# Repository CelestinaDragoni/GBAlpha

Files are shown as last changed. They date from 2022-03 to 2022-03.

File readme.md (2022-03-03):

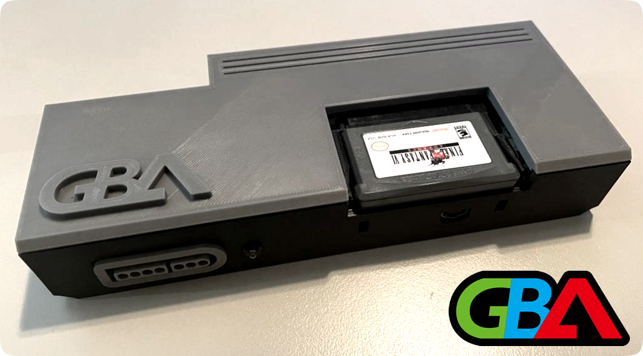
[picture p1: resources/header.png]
GBAlpha


# GBAlpha - *A Console-Like Case for Woozle's GBA Consolizer*

## Introduction
Included in this repository is a custom case design for Woozle's GBA Consolizer. This has a more console-like feel and has inspirations from various design choices from the PCEngine and NES. This case was designed around the maintainability of components inside being easy to disassemble and assemble and, unlike other available cases, this is a complete project with documentation, assembly, and printing instructions. If you want to know more around my thoughts and this project please read my forward [here](docs/introduction.md).

## Table of Contents
- [Expanded Introduction / Forward](docs/introduction.md)
- [Image Gallery](docs/gallery.md)
- [Materials Required](docs/materials.md)
- [Printing Instructions / Suggestions](docs/printing.md)
- [Assembly](docs/assembly.md)
- [STL Index](stl/readme.md)

## How To Download
Click `code` at the top and `Download Zip`, or if you're a champion checkout with `git`.

## Donate
If you like this project and want to help me stay caffeinated you can donate here: https://www.paypal.com/donate/?hosted_button_id=852RXAG6BF8Y8

## Disclaimer
This project isn't endorsed or supported by Woozle or anyone affiliated with the GBA consolizer or related projects like the GBA HD. This is my own thing. Don't go asking anyone else for support or help with this case and its designs. Thanks.

## General License



This work is licensed under a [Creative Commons Attribution-NonCommercial-ShareAlike 4.0 International License](http://creativecommons.org/licenses/by-nc-sa/4.0/).

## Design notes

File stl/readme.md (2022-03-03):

# STL Index

## Disclaimer
While you could just come in here and wing it, I highly recommend reading the [documentation](../readme.md) before throwing this into a slicer and having a go at it. This is a large print and a lengthy one at that. However, you do you.

## ./
### Cart Slot `cartslot.stl` (Required)
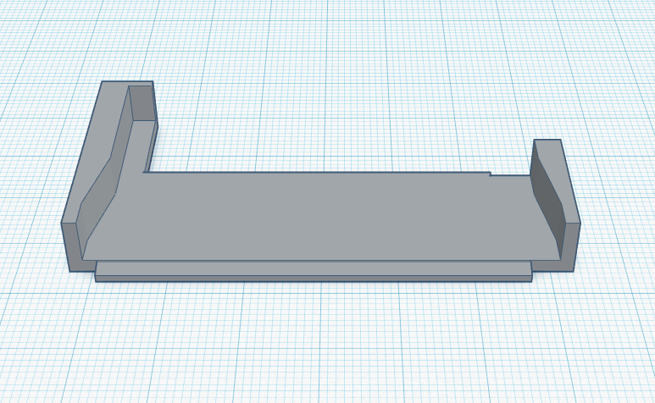
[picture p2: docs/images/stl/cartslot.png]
Cart Slot Render


This is Woozles cart slot model. This case reuses this part from that case as it was a pretty clean way of making a cart slot. You will need to print this for full assembly.

### GBA Logo `logo.stl` (Optional)
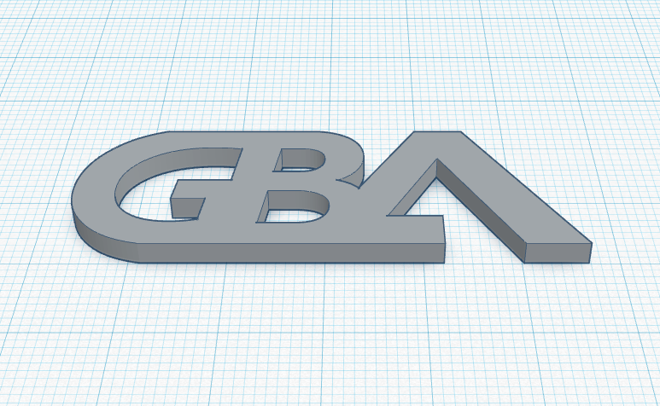
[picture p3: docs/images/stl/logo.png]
Logo Render


This logo is to be paired with the lid with no logo so could have have two colors on your lid.

## ./bases
### Base Full `base-full.stl` (Recommended Variation)
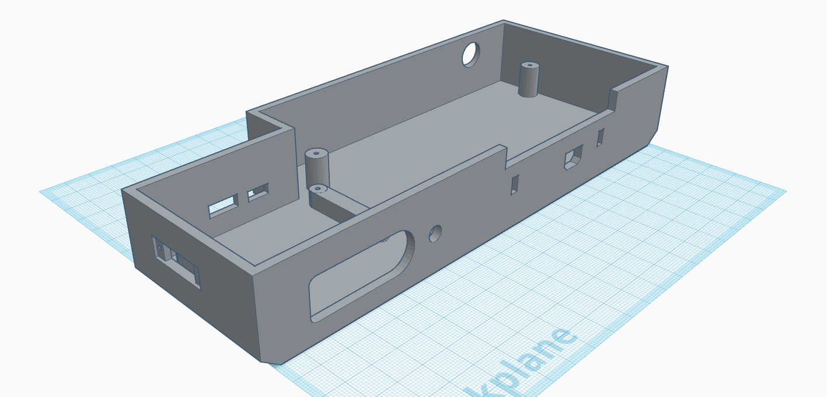
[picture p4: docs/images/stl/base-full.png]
Base Full Render


This includes everything of the base base, the GBA game link adapter slits, microphone jack in the back, etc.

### No GBA Game Link `base-no-gba.stl` (Optional Variation)
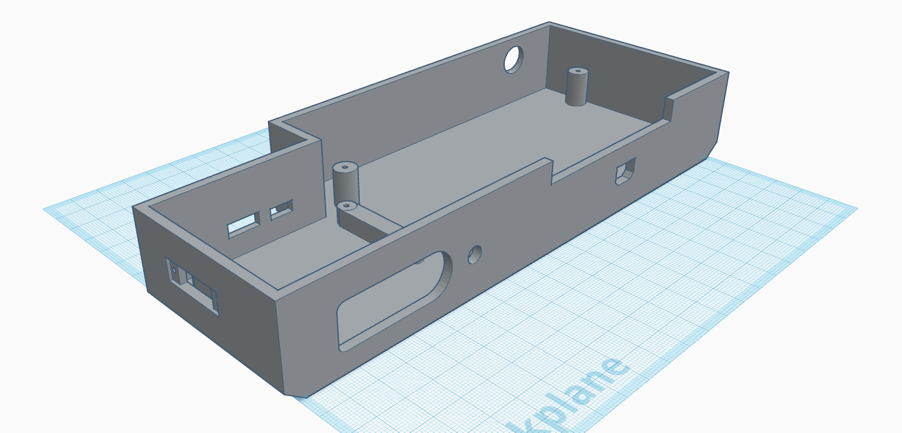
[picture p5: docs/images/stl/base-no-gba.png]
Base No GBA Render


This variation of the base has no slits for the GBA link cable accessories though still provides the GB link cable port. Outside of maybe the infrared adapter, you're likely not going to be sitting with two TVs or switching inputs to play four swords or search for Triforce pieces in Wind Waker. This is makes the front of the case much cleaner and is a good variation for those who don't care about GBA connectivity.

### No Microphone Port `base-no-mic.stl` (Optional Variation)
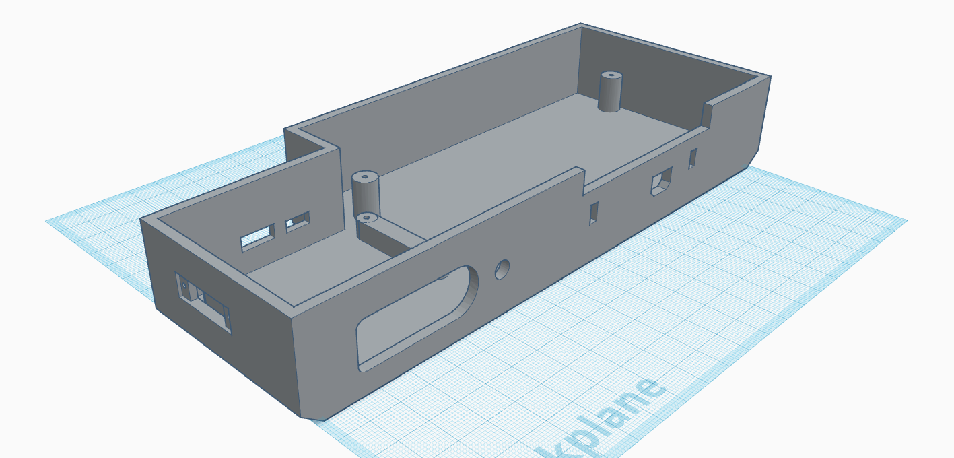
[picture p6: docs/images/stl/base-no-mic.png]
Base No Mic Render


This variation of the base has no microphone port on the back. This is provided to those who don't need access to it and DVI+ works just fine and want a cleaner back.

### No GBA Game Link & No Mic `base-no-gba-no-mic.stl`  (Optional Variation)
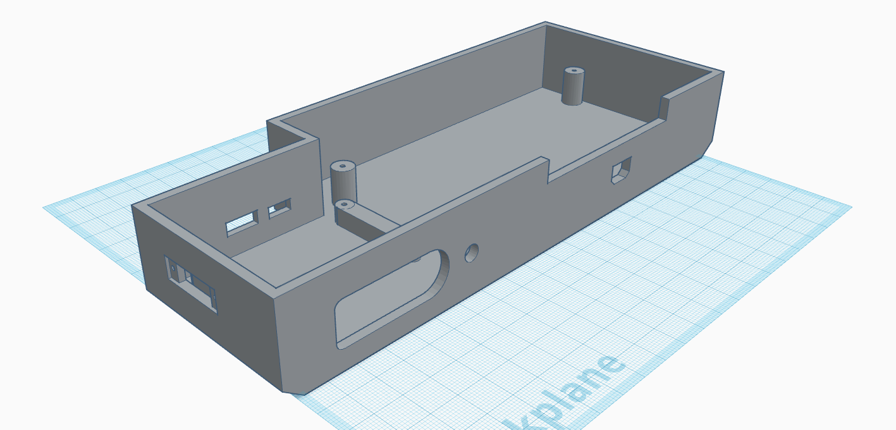
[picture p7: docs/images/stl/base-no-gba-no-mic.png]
Base No GBA No Mic Render


Combines the no microphone port and the lack of GBA game link slits.

### Absolute Minimalism `base-minimal.stl` (Optional Variation)
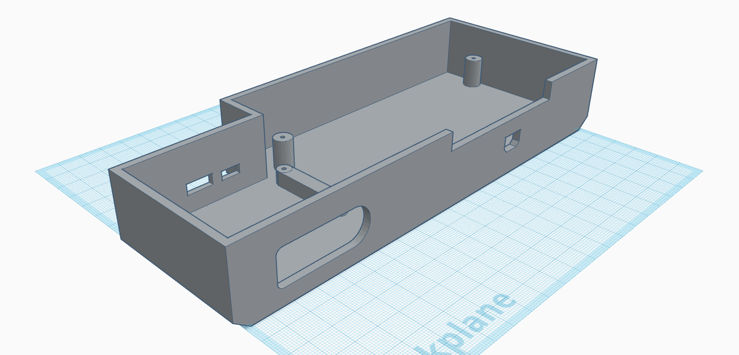
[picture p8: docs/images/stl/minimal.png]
Base Minimal Render


Removes GBA game link slits, LED hole, microphone jack, and power switch. Truth be told when I originally was just modifying Woozle's case this was what I was aiming for so I could just not have to do any work and just get a USB PSU with a power switch on it (Like one used for a Raspberry Pi). This is a minimum effort and minimum part case and all you'll need outside of the mod itself is eight (8)  `M2*6` screws.

**Note:** To use this variation you will need to solder bridge the first two (left to right) pads of the power switch area (P2 and P3) on the PCB so that when it is plugged in it will stay on. Honestly trivial thing to do considering you already did the rest of the mod.

## ./lids
### Lid With Logo `lid-full.stl` (Recommended Variation)
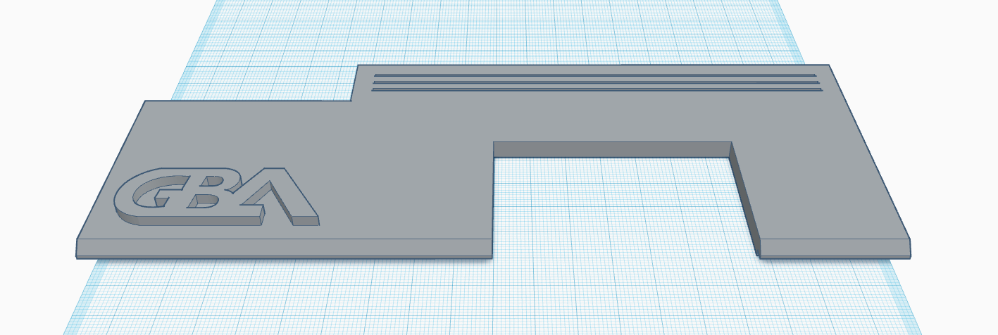
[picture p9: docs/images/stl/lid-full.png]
Lid Full Render


This comes with the GBA logo on the top already embossed on.

### Lid With Without Logo `lid-no-logo.stl` (Optional Variation)
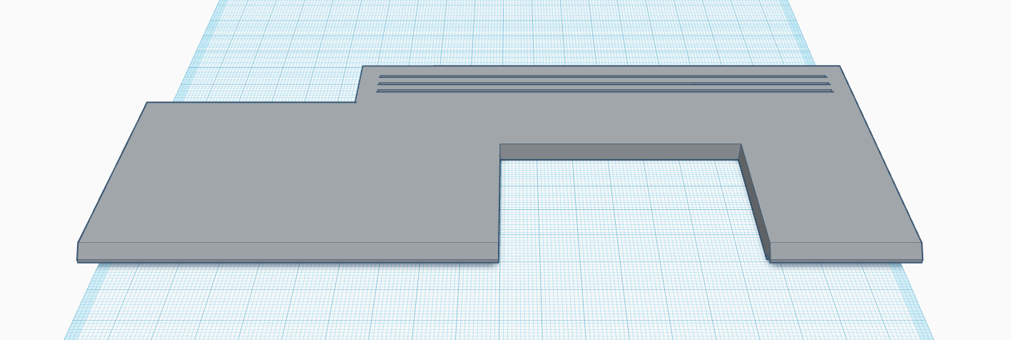
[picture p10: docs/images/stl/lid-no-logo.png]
Lid No Logo Render


This is the same lid but without the logo. You could just print this and use it without a logo at all OR you could print the logo by itself (see `./logo.stl`) in another color and glue/attach it to this lid to make a duotone lid. Alternatively if you have an IDEX 3D printer you could just combine those two models and print with two colors.

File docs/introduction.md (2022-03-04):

## Navigation

- [Home](../readme.md)
- [Expanded Introduction / Forward](introduction.md)
- [Image Gallery](gallery.md)
- [Materials Required](materials.md)
- [Printing Instructions / Suggestions](printing.md)
- [Assembly](assembly.md)
- [STL Index](../stl/readme.md)

# Expanded Introduction / Forward
This includes all of my thoughts around this project and various rants. If you're uninterested in reading this please feel free to skip along to the materials list.

## Who Am I?
I'm a Software Engineer from Raleigh NC and a retro gaming enthusiast. I own a few modded consoles and worship our lord and savior ***Lord Voultar*** ([Shop](https://voultar.com/), [YouTube](https://www.youtube.com/c/Voultar)). Unrelated, I'm also a cat girl omnicrafter in Final Fantasy XIV.

## Why Did  I Make This?
About six months ago I ordered a kit from game-tech.us and it finally came in. It came with the v2 kit (FFC/Flex Cables) and the Laser Bear Industries case. After getting the kit installed on the hardware itself it was time for assembly into the chassis.... That would end up being a disaster and send me down this rabbit hole of engineering this case.

## The Issues With Existing Cases

### Short Notice Before We Proceed
I want to be clear, I'm not putting down anyone's work  or their contribution to the community efforts. I (personally) appreciate everything everyone does to help move these projects along and makes things awesome. However, I think criticism is warranted to help make things better because feedback is rarely given around these projects.

---

### Laser Bear Industries Case
Case Link: https://www.laserbear.net/products/gba-consolizer-shell-laser-bear-version

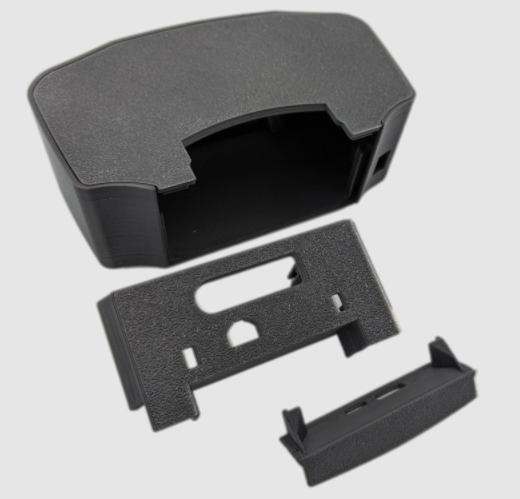
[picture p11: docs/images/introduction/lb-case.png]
LB Case


*Source: Laser Bear Industries*

I want to say some positives first off before I really dive into what I dislike about this case.

- It was extremely well printed and clean.
- The components were well fit (too well fit, and we'll get into that in a moment).
- The case came with everything you needed to assemble it.
- They also provide STL so you can download it and print it at home: https://www.laserbear.net/pages/downloads

#### Problem 1: Too Tight of Fit, Tight Tolerances
Getting things in there is quite easy if you follow how to do it, however if something came loose or something is borked that you didn't noticed before assembly, good luck getting your components out of the case without breaking it in half (which is what happened eventually).

The part to assemble the back and the front where the SFC/SNES port is have to be perfectly align, the tolerances were so tight you had to really put force down on these to get them in and snap. I really dislike this, I would have much preferred a mounting setup that would require hardware.

#### Problem 2: The Power Switch
You know, the consolizer has a place to put pins for a DuPont connector or a surface mount switch so I find it absolutely wild that this case didn't have the clearance to do so. Furthermore- the power switch 'bracket' (the place on the side of the case to insert the PCB) is too hard to get to and too hard to assemble.

#### Problem 3: Design (Subjective)
I think it's an unattractive case and still has that project box feel. I'm not about it, I also don't like the power switch cover I think it's tacky and would have just preferred the power switch PCB to be mounted closer so I can just use the vanilla switch. However this opinion is on me and my tastes and there is nothing inherently wrong about it.

---

### Woozle's GBA Consolizer Enclosure
Case Link: https://www.thingiverse.com/thing:4522648

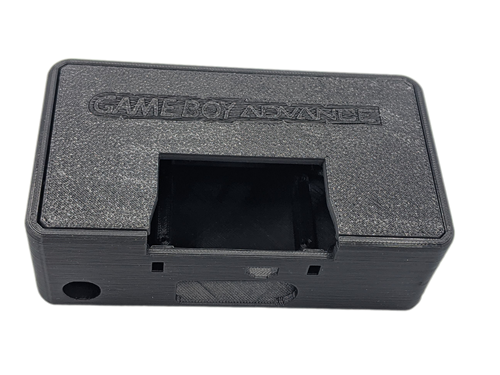
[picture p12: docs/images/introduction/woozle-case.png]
Woozle Case


*Source: Laser Bear Industries*

**I actually really like this case** and after the debacle with the LB case I decided to print this one up at home (Note, prior to buying the kit months ago I didn't have a printer at the time, I do now). Let's get into what I like about this case:

- Pretty easy to print which is good (with some exceptions we'll get into that shortly)
- Pretty hefty and nice feeling (had some weight which was a complaint about the LB version)
- Hardware mounting for the consolizer PCB and the GBA PCB
- Well fitting but enough tolerances not to be a complete pain in the ass to reassemble and disassemble.
- Love the cart slot design (which would be carried over to this project)

However...

#### Problem 1 - Where Is The Documentation?
So currently on thingiverse the only thing mentioned is this:
```
Other parts:
10x4mm pin magnets (4)
10x2mm disc magnets(4)
6mm M2 screws (8)
```
This is great but:

1. Where do I source these pin/disc magnets? I scoured amazon for hours trying to find something that matches this and came up either confused or empty. I would like some examples as to what can be used so I can find the correct fitting items.
2. There is no talk about the power switch or button here. There is room for some sort of button (I've seen variations with a push button and ones with a toggle switch) but no clear definition on what I should purchase for the case.
3. What is the extra hole next to the power switch for? An LED power indicator?
4. This print will naturally build a bunch of supports that aren't required. Some guidelines on what should be supported and what shouldn't be (like overhang tolerances and angles) would be much appreciated.

#### Problem 2 - The Lid

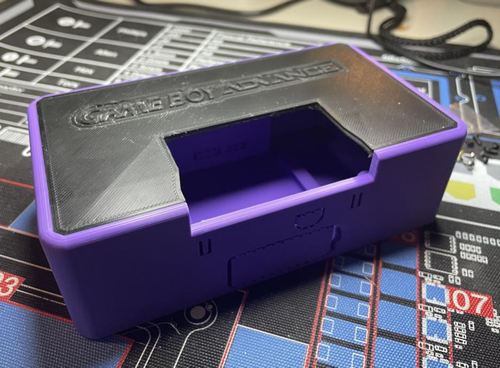
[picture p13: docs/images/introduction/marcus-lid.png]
Marcus Lid


While I appreciate that an SVG was given so I could make a plexiglass lid, I didn't want that personally. Now I know that [marcus9199](https://www.thingiverse.com/marcus9199) made a lid ([link](https://www.thingiverse.com/thing:4535786)) and it was *fine*, but again needed these mystery magnets to make it work work.

Just to note, I don't like magnets as a mounting hardware to begin with (This is the exact reason why I threw a Razor Naga in the trash some eight years ago). Furthermore an inset logo will always look worse printed than embossed, just the nature of FDM. I ended up making a lid modification with a thru-holes for screws and a cleaner logo as a result while I was trying to make this case work for me.

#### Problem 3 - Design  (Subjective)
Again, felt like a project box- but that is just on me.

#### Some Resolution - Modifications I Made To Make This Case Functional
I would end up making the following modifications so that I could use the case:

 - Made a new lid that could be screwed in so I didn't have to deal with magnets.
 - Gave the lid a new embossed logo so that it wouldn't look scuffed.
 - Removed the power button entirely in favor of USB inline power button (Much like one on a Raspberry Pi)
 - Fixed a problem with the model where  there was a missing line (I assume a seam) in the model.

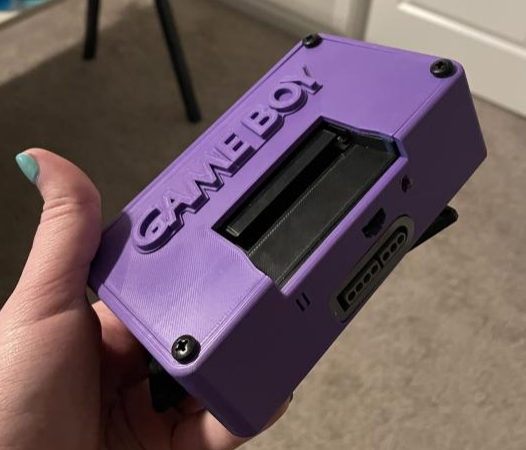
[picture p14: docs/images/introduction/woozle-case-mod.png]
Woozle Case Mods


These modifications would reduce the amount of headaches around the missing documentation and give me a complete console case that looked clean.

However I still wasn't satisfied after my work on this, it felt incomplete, this felt like a hack and I hated it.

## Designing A New Case

### Frustration Leads to Creation
After being effectively demoralized by all this work I did above, I ended up finally gaining the courage to just design a case from scratch. I had never done 3D CAD work before, however in a past life I used to be a engineer for architectural signage so a lot of that just kinda crossed over pretty seamlessly. The biggest challenge was finding software. I run Linux (Arch) because I mainly do development and Windows+Microsoft can fuck right off. However, this choice leaves me with very limited options for CAD software outside of going and buying a MacBook. Thankfully TinkerCad was more than enough to get the job done and to build out the part assembly.

### Case Design Goals
Before starting, just like any engineering project, I wanted to get my goals straight. Here is where my mind was at:

 - Can be printed on pretty much any basic FDM printer (The litmus test for this is an Ender 3, which is what I have)
 - Assembly and disassembly is easy and not frustrating. Using mounting hardware for the PCBs
 - Items required for the case should be easily available and be documented for those who wish to build it.
 - Have alternative options for those who might not want certain features in the case.
 - **Looks like a console**, remove the stacked design of the other two cases for something that looks more like something you would buy in a store.

### Design Inspirations
Look no further to console designs that sport the front-loading design. Elements of the NES and the PCEngine/TG-16 were massive inspirations for this project. However, since this also had an SNES/SFC port, I wanted some lingering elements of a SFC as well to bring it together.

### Design Challenges
- Woozle's flex cables are short in length, we will have to extend them to work in a flatter console design.
- Have enough tolerances for soldiering differences on the controller ports as well 3D print variation while not looking sloppy.
- Figure out the mounting mechanism for the lid and the base that would be easy to print and take on/off as needed.

### Early Designs / Prototypes
I first started off with a 2D drawing to get my head in the right place, below is an early example of the design.

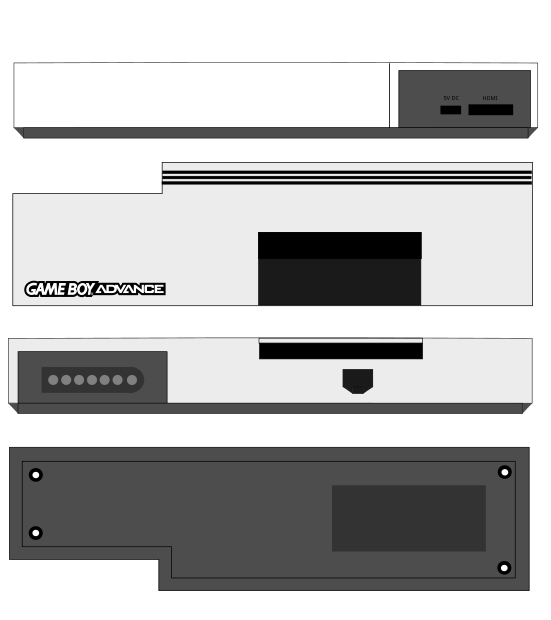
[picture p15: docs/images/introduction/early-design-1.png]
Early Design


From there I started modeling this design and picking apart parts of it to ensure form and fit.

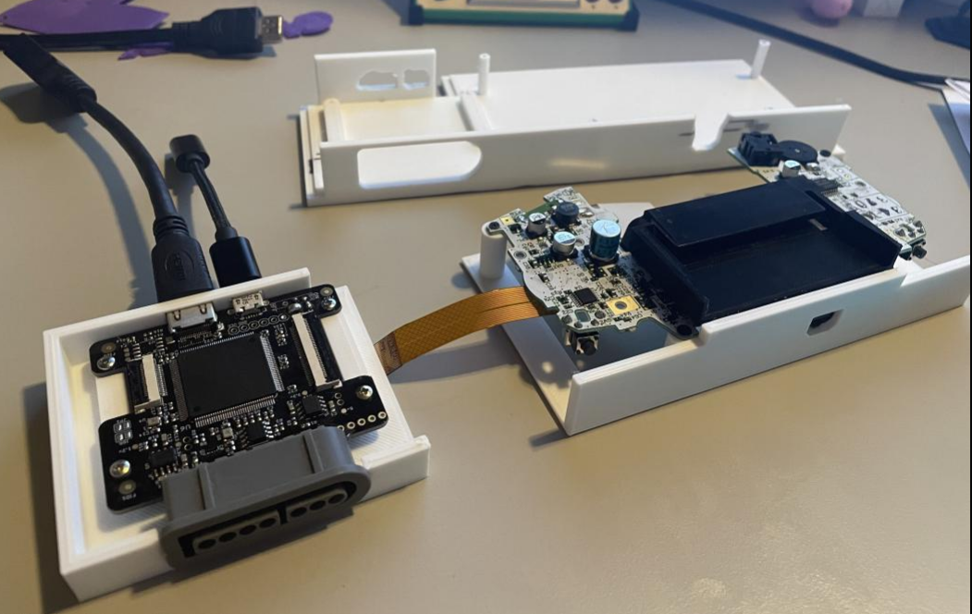
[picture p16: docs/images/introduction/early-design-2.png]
Early Design 2


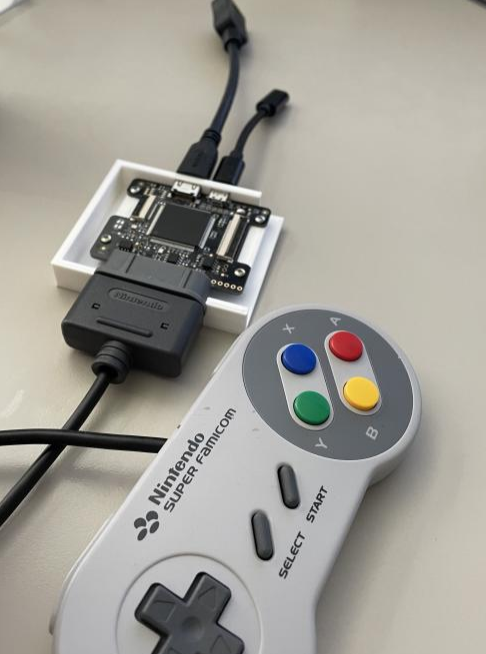
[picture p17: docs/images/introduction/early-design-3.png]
Early Design 3


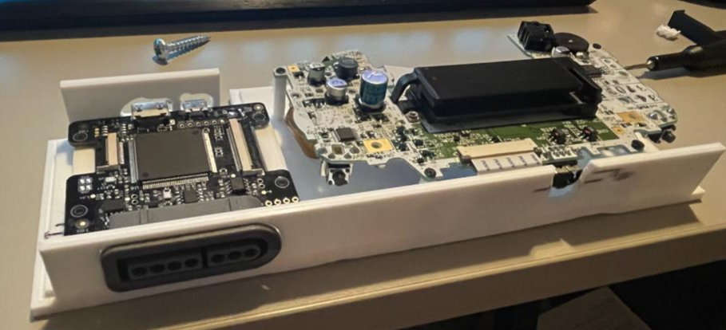
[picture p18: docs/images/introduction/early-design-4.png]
Early Design 4


At the end of it I would end up being a model something like this:

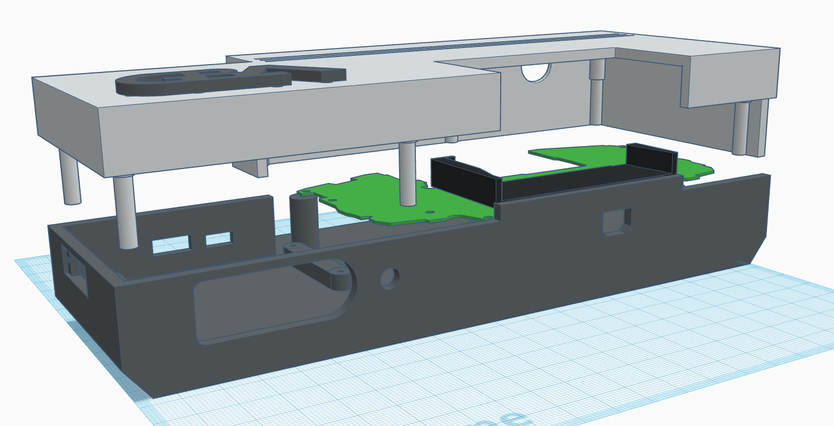
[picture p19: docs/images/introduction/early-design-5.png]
Early Design 5


**I thought this would have been the end of it** ...however, it was not...

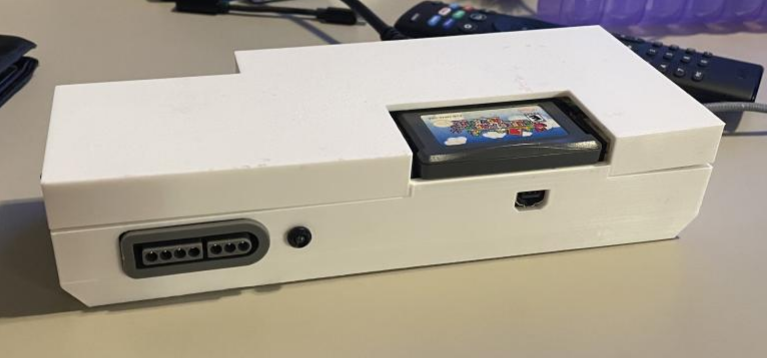
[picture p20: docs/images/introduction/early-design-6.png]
Early Design 6


This design had a lot of challenges that maybe someone more technical could have overcame, but I was dissatisfied:

 - Case fit tolerances didn't go as expected, bowing in the case as a result of the screw mounts.
 - Converting injected molded design concepts into an FDM printed one wasn't a great idea for various reasons.
 - Furthermore it was entirely too difficult to print- the countersunk screw holes at the bottom were extremely problematic to print consistently and cleanly. The lid top was never cleanly printed despite how level my bed would be.
 - Screws would break in the mounting holes because of far too much torque required to put them in.

### Redesign and Compromise
 I would need to return to the drawing board after weeks of work and hours of printing prototypes.  Thankfully Elden Ring wasn't out yet so I wasn't distracted from my goal. After analyzing my failures and effectively botching some of the main goals, I decided to take this approach:

 - Remove screw mounting entirely from the base and lid. This not only made it hard to print, but made it horrible to assemble and was too complicated.
 - Make the lid snap on tension. This will make it easy to print and make it easy to remove. However it would need to be tight enough to pass the 'blizzard test'.

As a result of those compromises, this would end up being the final design:

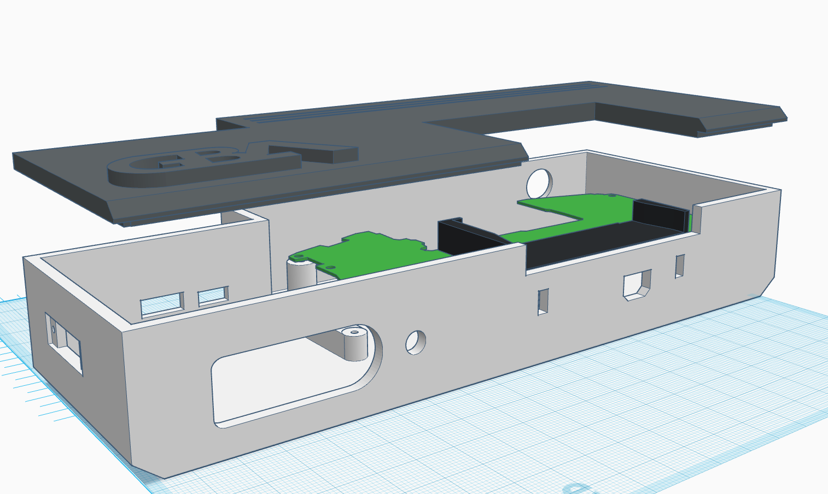
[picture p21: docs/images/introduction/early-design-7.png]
Early Design 7


It did, however take me like 6 different lid designs to get the form and fit right. The biggest issue is tolerances. I put in enough extra material on the lip to fit snugly and snap in, while not being an issue with the connectors for the LED and Power on the board itself.

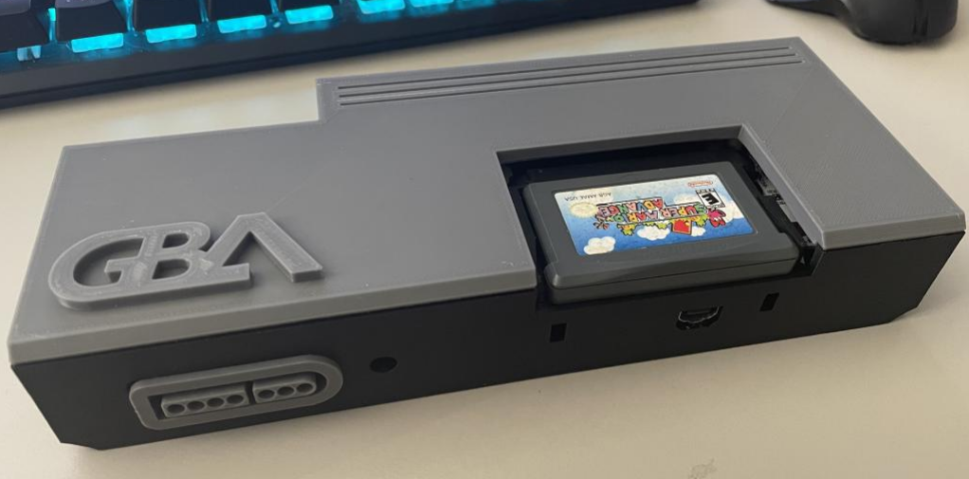
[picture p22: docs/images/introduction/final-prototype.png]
Final Prototype


The final prototype would make me very happy with the end result (though quite the deviation from the original design)

## Things I'm (Still) Dissatisfied With
While I'm extremely pleased with the design I did, there could be some improvements.

 - I hate the power switch. Originally I had it mounted inside where the mounting hardware would not be visible, unfortunately it is impossible to screw it in when the whole base is printed. As a result, to meet my goal of maintainability I went with mounting it on the outside. It's not hideous, but I wish it was nicer.
 - Tighten up some tolerances- the SFC port has some give to ensure depending on how exactly you mounted your port fits regardless, however it leaves some gaps. The lid could maybe use a bit more to snap more firmly into the case but I fear bowing of the lid as a result.

I may return to these in a revision if I get time or have the energy.

## The Last of It (Also a GBA HD Note)
This was a journey and over a month of work to get this functional and to my required spec. I'm pleased. If you have any suggestions or concerns please feel free to file it into the issues here in GitHub, I cannot promise I will get to them in a timely manor.

One last thing, this ephemeral `GBA HD` I keep seeing people talk about but I have no idea where to get one. **If someone wants to help me get my hands on one, reach out to me and I will be more than happy to make a revision of this case for that mod.** But until then, this is for Woozle's mod only.

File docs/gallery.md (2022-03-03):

## Navigation

- [Home](../readme.md)
- [Expanded Introduction / Forward](introduction.md)
- [Image Gallery](gallery.md)
- [Materials Required](materials.md)
- [Printing Instructions / Suggestions](printing.md)
- [Assembly](assembly.md)
- [STL Index](../stl/readme.md)

## Image Gallery

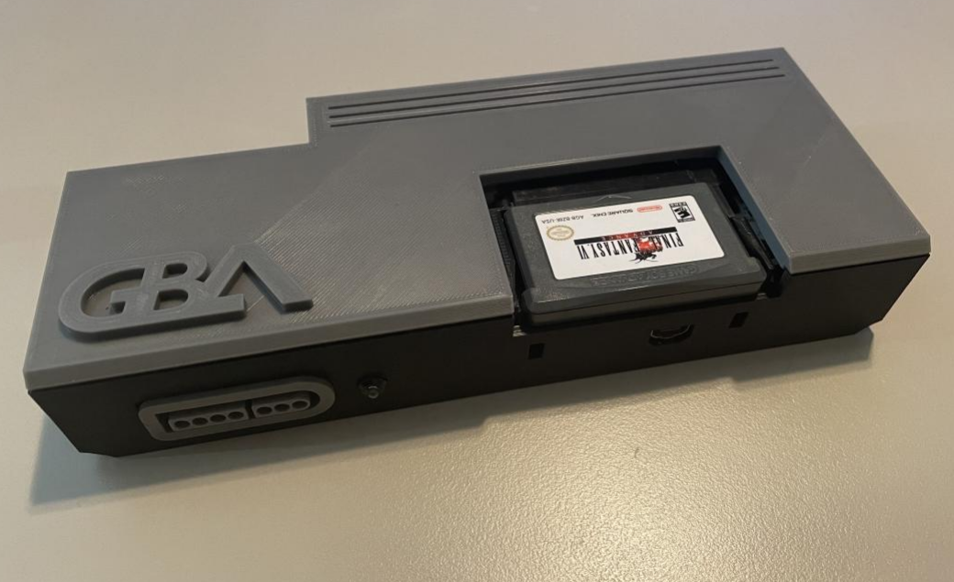
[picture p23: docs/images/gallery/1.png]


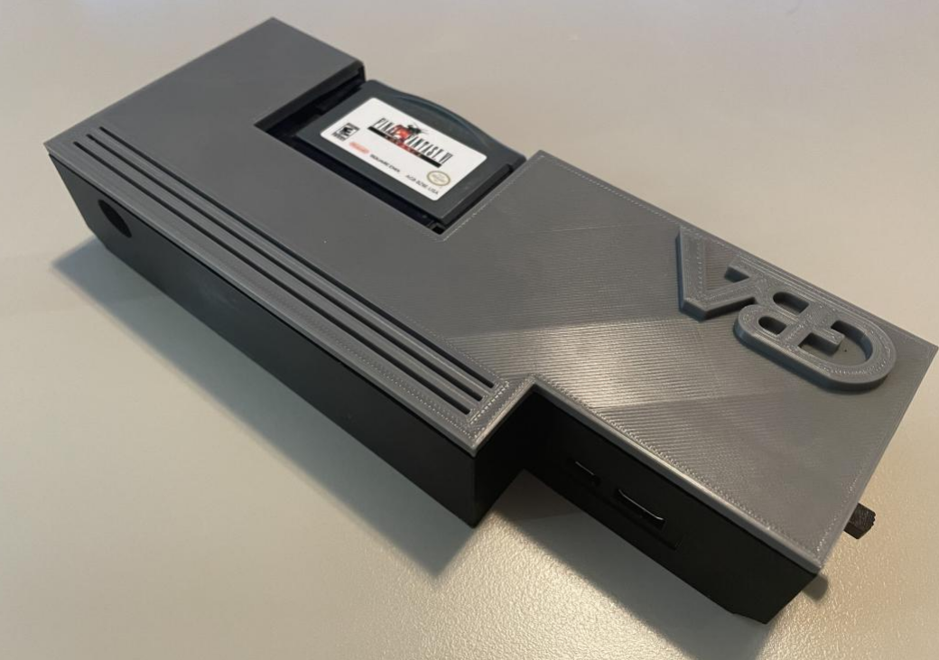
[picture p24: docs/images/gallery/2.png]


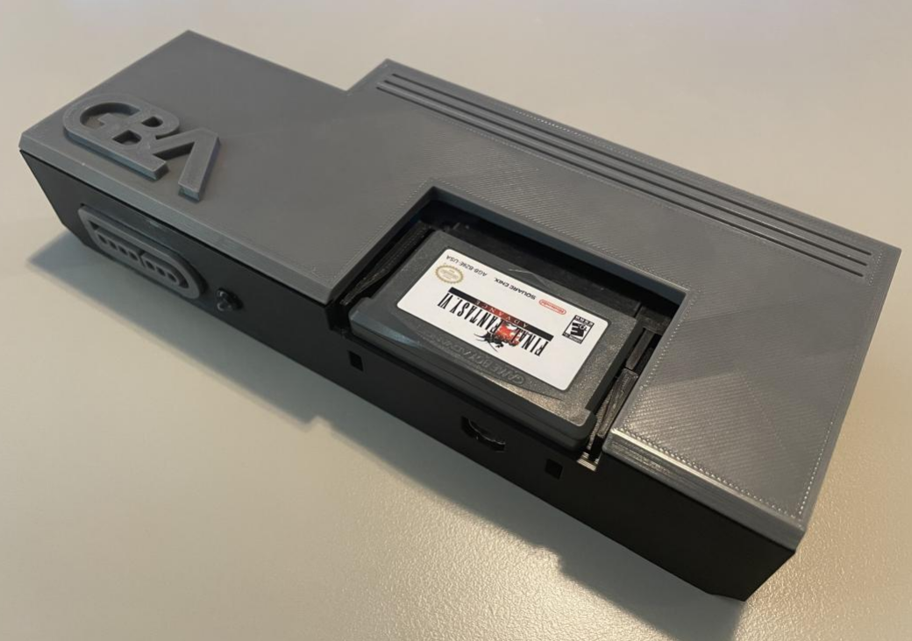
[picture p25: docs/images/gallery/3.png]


G

G

G

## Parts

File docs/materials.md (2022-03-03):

## Navigation

- [Home](../readme.md)
- [Expanded Introduction / Forward](introduction.md)
- [Image Gallery](gallery.md)
- [Materials Required](materials.md)
- [Printing Instructions / Suggestions](printing.md)
- [Assembly](assembly.md)
- [STL Index](../stl/readme.md)

# Equipment and Materials
**Note:** None of the links in this guide are affiliated. I hate that and I won't do it to you. Also, I'm going to assume you have a soldering iron here, you didn't make this far without one.

## 1. FDM 3D Printer
Obviously you're going to need one of these, however you need to make sure it will fit the case. The dimensions of the GBAlpha are as follows:

- **Base**: 208.5mm (W) x 84mm (D) x 33mm (H)
- **Lid**: 208.5mm (W) x 84mm (D) x 8.39mm (H)

This will print on an Ender 3 just fine (I use an Ender 3 V2), however if you have a smaller bed (like the Max Creator) you won't be able to print this object.

Furthermore, I highly recommend some sort of auto bed leveling such as a BLTouch or a CRTouch, this will help make your prints far more successful since these are chonky and adhesion can be an issue.

I have not tried this on a resin printer because I do not own one, but I don't see why you couldn't assuming you have a large enough print area.

## 2. Printing Filament
I just used PLA and this entire guide is around using that- brands I used while doing this project were:

 - Amazon https://www.amazon.com/gp/product/B07T6VTG5Q
 - Overture https://www.amazon.com/gp/product/B07VFQS5J3
 - SUN https://www.amazon.com/gp/product/B07ZNHTZ2T

However, use whatever you like. If you want to attempt to use more exotic materials, my printing guide will be of no help to you, you are on your own.

## 3. FFC and FFC Extensions (Flex Cables)
You are going to need these to make the case work because Woozle's cables are hard-wired to the board also the included cables are too short and won't reach otherwise.

### CPU Extension
- 1x 20 Pin 0.5mm FFC Cable (Type A): https://www.amazon.com/gp/product/B07RT6YHYD
- 1x 20 Pin 0.5mm FFC Extender: https://www.adafruit.com/product/5203

### Display Extension

#### Option A (Your GBA has a standard 40 pin FFC)

- 1x 40 Pin 0.5mm 150mm FFC Cable (Type B): https://www.amazon.com/gp/product/B0928Q1N2Z

#### Option B (Your GBA has to use Woozle's FFC)
**Warning:** This is untested, I do not have one, but logically this makes sense like the CPU extensions. However, as noted, I provide no warranty anyways, use your noodle.

- 1x 40 Pin 0.5mm 150mm FFC Cable (Type A): https://www.amazon.com/gp/product/B07S1C68C3
- 1x 40 Pin 0.5mm FFC Extension: https://www.adafruit.com/product/4523

## Variation Materials
Pass this point you will need to make a choice on which variation of the case you want to make. All the variations except the **minimalist variation** will need everything below. For the **minimalist variation** all you will need eight (8) `M2*6` screws and how to get them will be linked below. To see these variations look at the [STL index readme](../stl/readme.md).

## 4. M2 Screws
For the case and the power switch you will need:

- Eight (8) M2 * 6 Screws
- Two (2) M2 * 4 Screws (For the power switch, alternatively you  can just use M2*6)

Honestly buying a set of them is dirt cheap and useful to have, these are the ones I purchased: https://www.amazon.com/gp/product/B08NVVZC7Y

## 5. Power Switch
You just need a two position ON/ON power switch toggle, here is the one I purchased and used on the case:
https://www.amazon.com/gp/product/B007QAJWYW

## 6. LEDs and LED Holders
This case uses 3mm LEDs. These will be going into a 3.3v lead so if you're going to wire them yourself keep that in mind. However if you don't want to fiddle with all of that you can buy pre-assembled LEDs for not a lot of money:

- Pre-Wired LEDS: https://www.amazon.com/gp/product/B07X2YSQTQ
- 3mm LED Holders: https://www.amazon.com/gp/product/B08ZY6C6NC

## 7. DuPont Connectors and Crimps
This case is designed to be disassembled, so one of the things that will be done is that pins will be added to the FPGA board to easilly disconnect and reconnect the power switch and the LEDs. You will need these tools to do so. This kit is a good value and worked for my needs (it also comes with ribbon cable):

https://www.amazon.com/gp/product/B08D34JW68

## 8. Heatshrink
Since you're going to be making connections to the power switch, it's good to get those covered up. I'm not going to link to any specific brand here since they are all generally fine. You can just do a search like this and pick your fancy:

https://www.amazon.com/s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

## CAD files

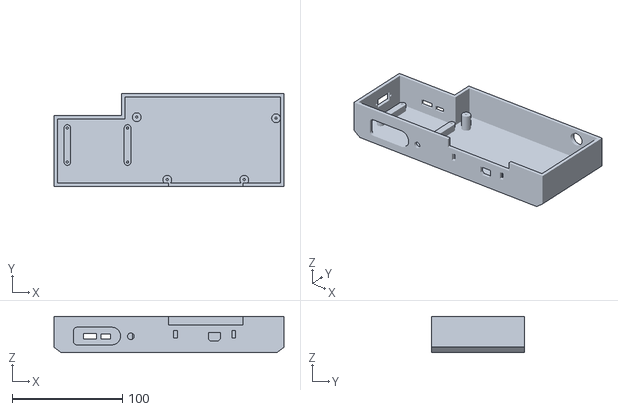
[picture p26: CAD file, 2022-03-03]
stl/bases/base-full.stl
208.5 x 84.0 x 33.0

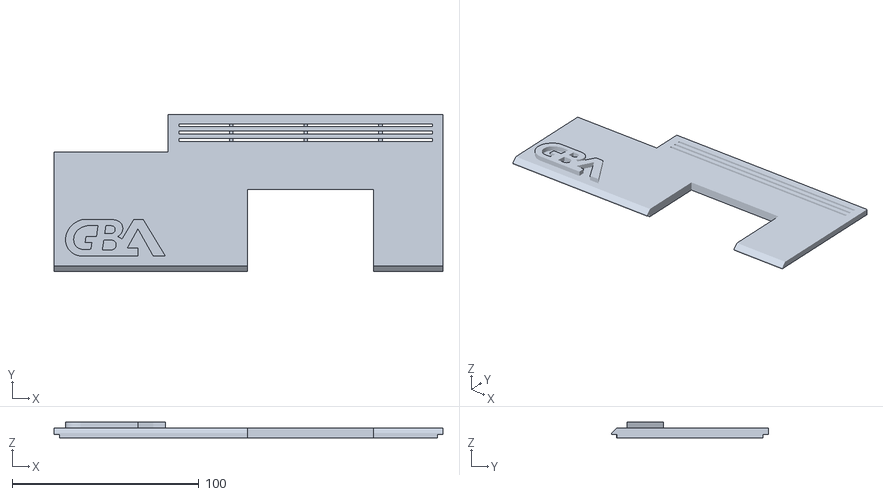
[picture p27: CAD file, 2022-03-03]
stl/lids/lid-full.stl
208.5 x 84.0 x 8.39

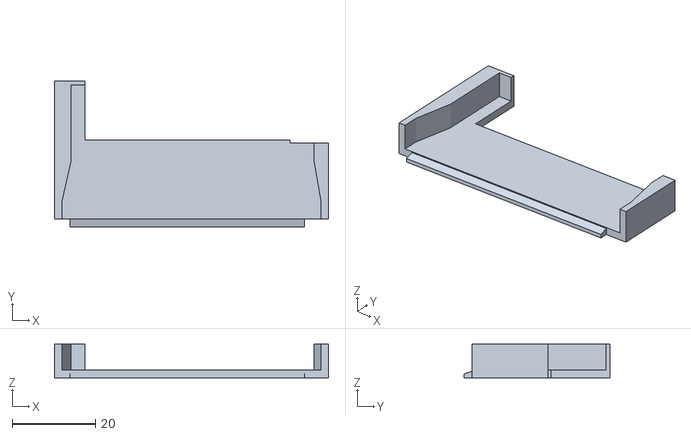
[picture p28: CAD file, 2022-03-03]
stl/cartslot.stl
66.0 x 35.3 x 8.10

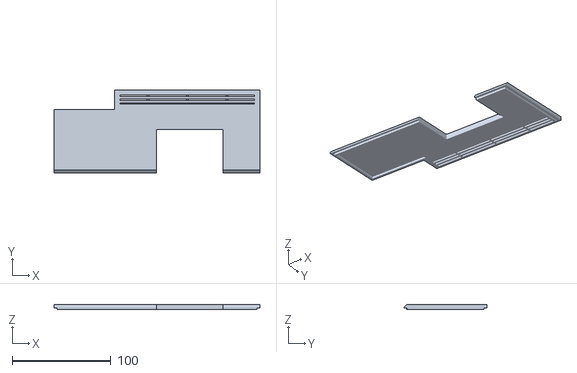
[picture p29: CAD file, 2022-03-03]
stl/lids/lid-no-logo.stl
208.5 x 84.0 x 5.40

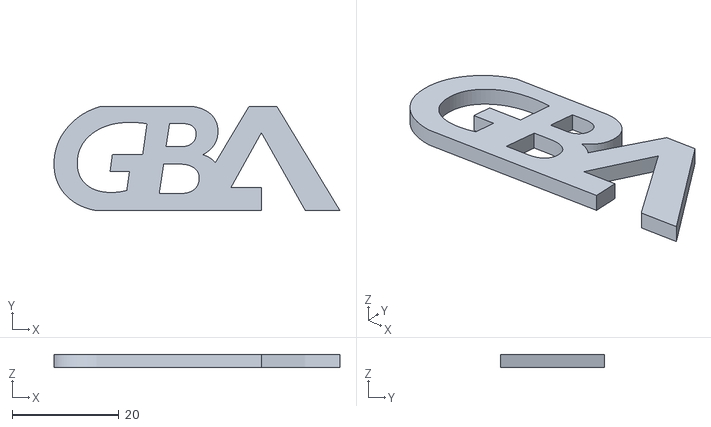
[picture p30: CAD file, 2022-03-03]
stl/logo.stl
53.5 x 19.5 x 2.50

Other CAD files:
stl/bases/base-no-gba.stl
stl/bases/base-no-mic.stl
stl/bases/base-minimal.stl
stl/bases/base-no-gba-no-mic.stl

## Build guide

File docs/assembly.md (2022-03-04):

## Navigation

- [Home](../readme.md)
- [Expanded Introduction / Forward](introduction.md)
- [Image Gallery](gallery.md)
- [Materials Required](materials.md)
- [Printing Instructions / Suggestions](printing.md)
- [Assembly](assembly.md)
- [STL Index](../stl/readme.md)

# Assembly
Your case has been printed and you're ready to go- here is how you assemble everything.

## Developer Note
My board in the picture looks scuffed because I've been doing work on it the entire time prototyping. Don't judge me.

## Minimalist Variation Board Prep
This guide is only used to prep boards using the minimalist case variation. If you're using any other variation that has the LEDs and power switch skip this section. **If you're using the minimalist case variation read this section and then skip to the final assembly section.**

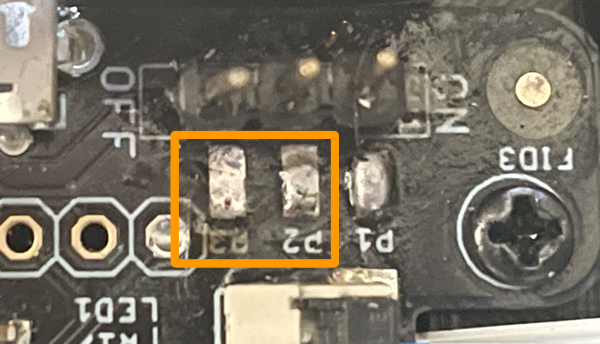
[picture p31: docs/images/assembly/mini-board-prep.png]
Mini Board Prep


All you need to do is bridge P3 and P2 on the board, this will make the board in an always on state when you plug it in.

## Normal Board Prep

You will need to take your flush pin connectors and cut two of them to have:
- 1x 3 Pin
- 1x 2 Pin

And then you will need to solder them to the board as shown in the picture. One is for the power switch and one is for the LED indicator.

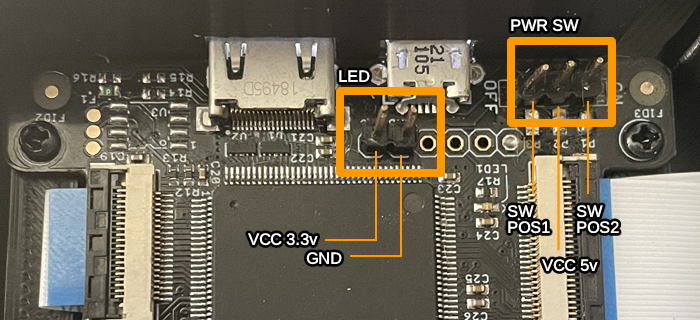
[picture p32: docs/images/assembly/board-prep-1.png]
Board Prep


## Power Switch Assembly

Here we will be wiring up your switch, I highly recommend coloring the middle pin something different as that is important.

- Measure three pieces of wire from the edge of the mounting hole to the connector, giving some slack so you may easilly insert it later.
- Strip one end of the wire.
- Pre-tin them if you haven't done so.
- Attach each wire to each pin of the switch with solder (Try to be somewhat liberal here).
- Heatshrink the ends to prevent exposure of the conductors.
- Take the other end and strip your wires, tin them, and crimp them with dupont connectors. (If you don't know how to do that please look here: https://www.youtube.com/watch?v=jET1QTP1B7c)
  - Pin 1 and 3 can go on either end.
  - Pin 2 NEEDS to go in the middle. Make sure you confirm this.
- Your power switch is good to go. I recommend testing this while the board is outside of the case.

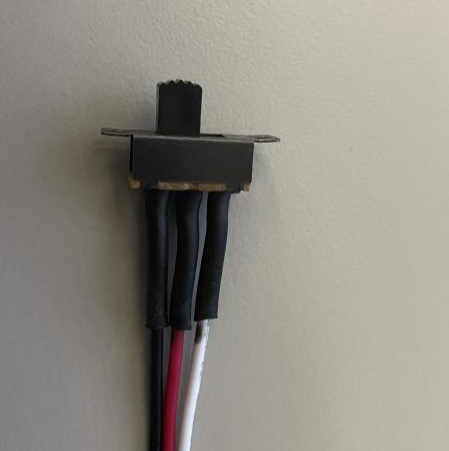
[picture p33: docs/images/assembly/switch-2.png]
Board Prep Switch

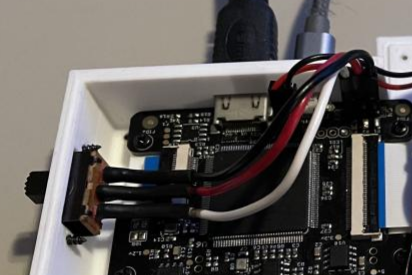
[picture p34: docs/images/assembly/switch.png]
Board Prep Switch


## LED Assembly

I'm going to assume you bought the pre-wired ones, if you didn't, you know the drill (LED, resistor, heatshrink, etc.).

- Cut the end of the wire without the LED to be short enough to have some slack to connect but not too long.
- Strip and tin your wires.
- Crimp and add a DuPont connector to the end as needed.
- Your LED is good to go, again I recommend testing this  while the board is outside of the case.

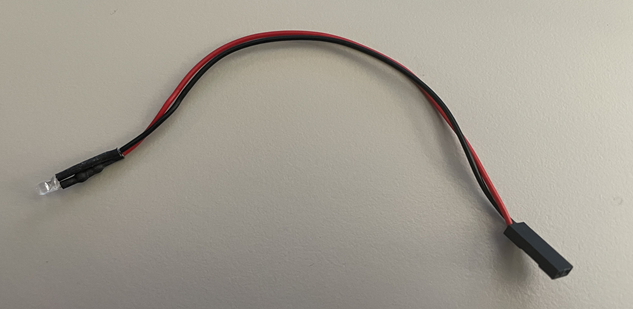
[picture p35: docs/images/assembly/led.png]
Board Prep LED


## Final Assembly

 - On your GBA motherboard, attach the FFC cables and extensions/replacements as needed.
 - Place down the GBA in the case on the right side aligning the screw holes.
 - Add the cart slot print in and make sure it clips into the front of the case where the slit is.
 - Screw in your GBA using four (4) `M2*6` screws, make sure you adjust it so that it is tight against the front of the case and the card slot component.
 - Now run your FFC cables over to the left side.
   - The CPU wire should go under where the FPGA board should go
   - The Display wire should go right by the where the FPGA board should go
- Now place in your FPGA board and make sure it is aligned correclty with the SNES/SFC port in the front and the mounting holes correctly.
- Attach the FFC cables to the left and right side accordingly.
- Screw in the FPGA board four (4) `M2*6` screws
- Now install your LED module
  - Connect the LED to your board.
  - Fish the LED through the front hole to the outside.
  - Place the LED inside of the holder.
  - And push the holder into the hole into the case, it should be snug.
- Install your Power Switch
  - Fish the wires through the hole on the side.
  - Mount the power switch with either two (2) `M2*4` or `M2*6` screws.
  - Attach the wires to the FPGA board (ensuring  the middle pin is connected to the middle)
- At this point I would do a test, turn the console on, make sure it works.
- Put the lid on, it should just snap in.
- Enjoy

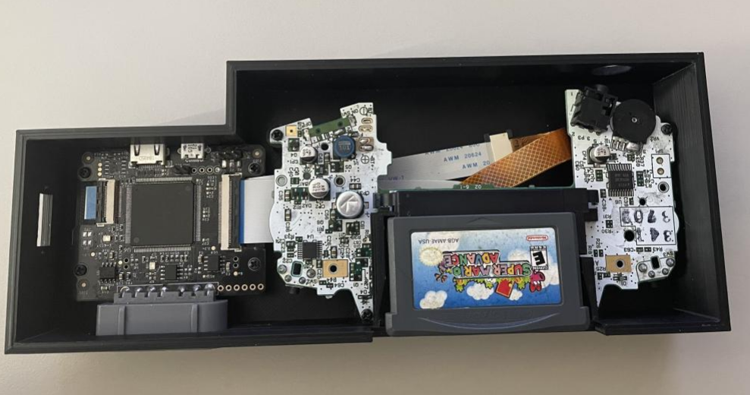
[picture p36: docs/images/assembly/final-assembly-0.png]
Final Assembly 0

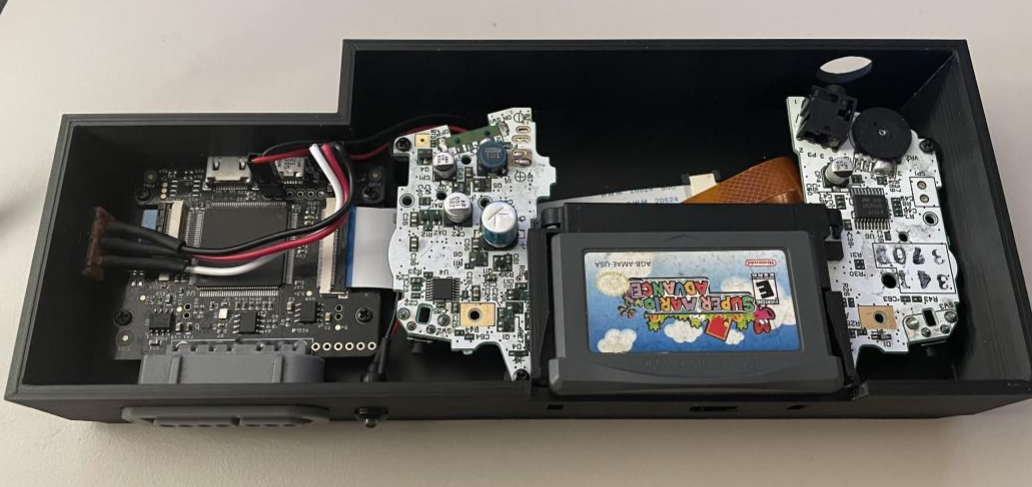
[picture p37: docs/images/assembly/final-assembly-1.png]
Final Assembly 1


## Finished Working Assembly

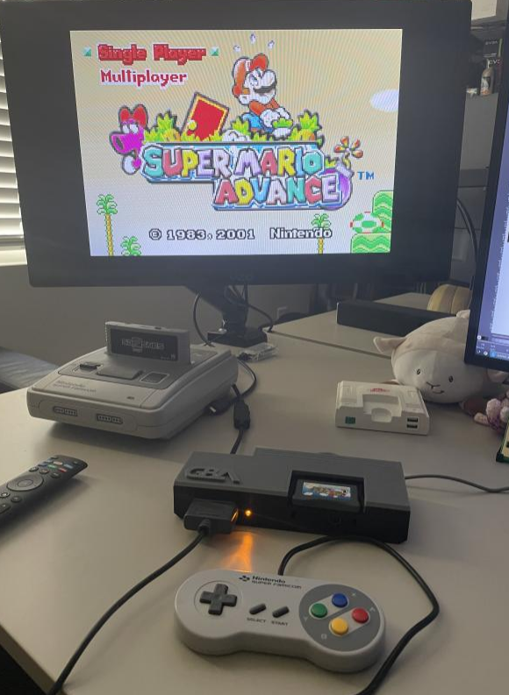
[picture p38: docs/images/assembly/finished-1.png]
Finished 1

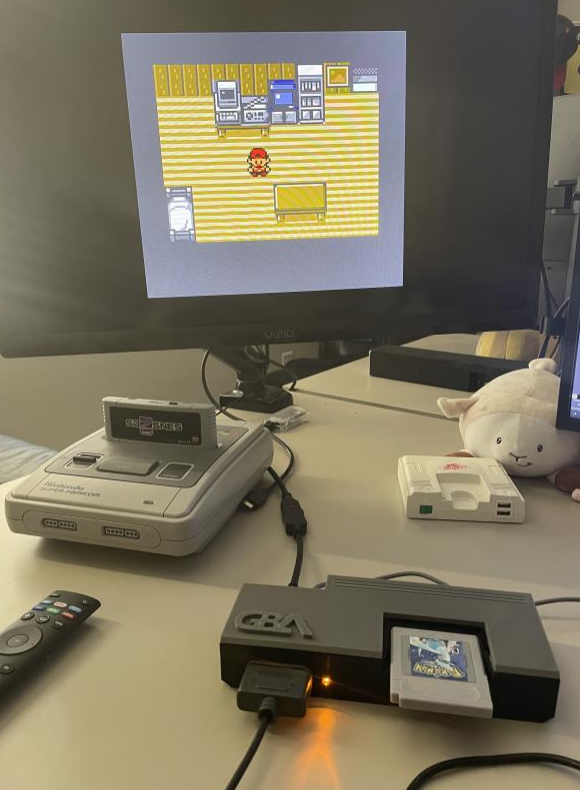
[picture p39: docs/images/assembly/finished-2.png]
Finished 2


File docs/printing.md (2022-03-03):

## Navigation

- [Home](../readme.md)
- [Expanded Introduction / Forward](introduction.md)
- [Image Gallery](gallery.md)
- [Materials Required](materials.md)
- [Printing Instructions / Suggestions](printing.md)
- [Assembly](assembly.md)
- [STL Index](../stl/readme.md)

# Printing Instructions / Suggestions
These are built around my Ender 3 V2 with a CRTouch- however they should work for nearly anyone who wants to print this. I used Ultimaker Cura to slice these prints, but any other slicer such as Prusa should also work just as well.

Also since I'm sure I'll give someone a migraine, I highly suggest printing these items on a **raft**. Yes you heard me, I will explain in further detail later why this is.

## Suggested Settings
|Property|Value|
|--|--|
| Cura Starting Profile | Super Quality
| Extrude | 0.2mm - 0.3mm |
| Extrude Temp | 200c (PLA)
| Bed Temp | 60c-62c (Glass) or 70c (PEI)
| In-Fill Density | 20-50% |
| In-Fill Pattern | Lines |
| Speed | 50/mm |
| First Layer Speed | 25/mm |
| First Layers | 4 |
| Supports | True
| Support Density | 5% |
| Minimum Support Area | 6mm |
| Support Overhang Angle | 80
| Adhesion | True
| Adhesion Type | Raft |
| Raft Margin | 5mm |
| Raft Air Gap | 0.45mm (This was for at .2 extrude for me, adjust accordingly) |

## The Base
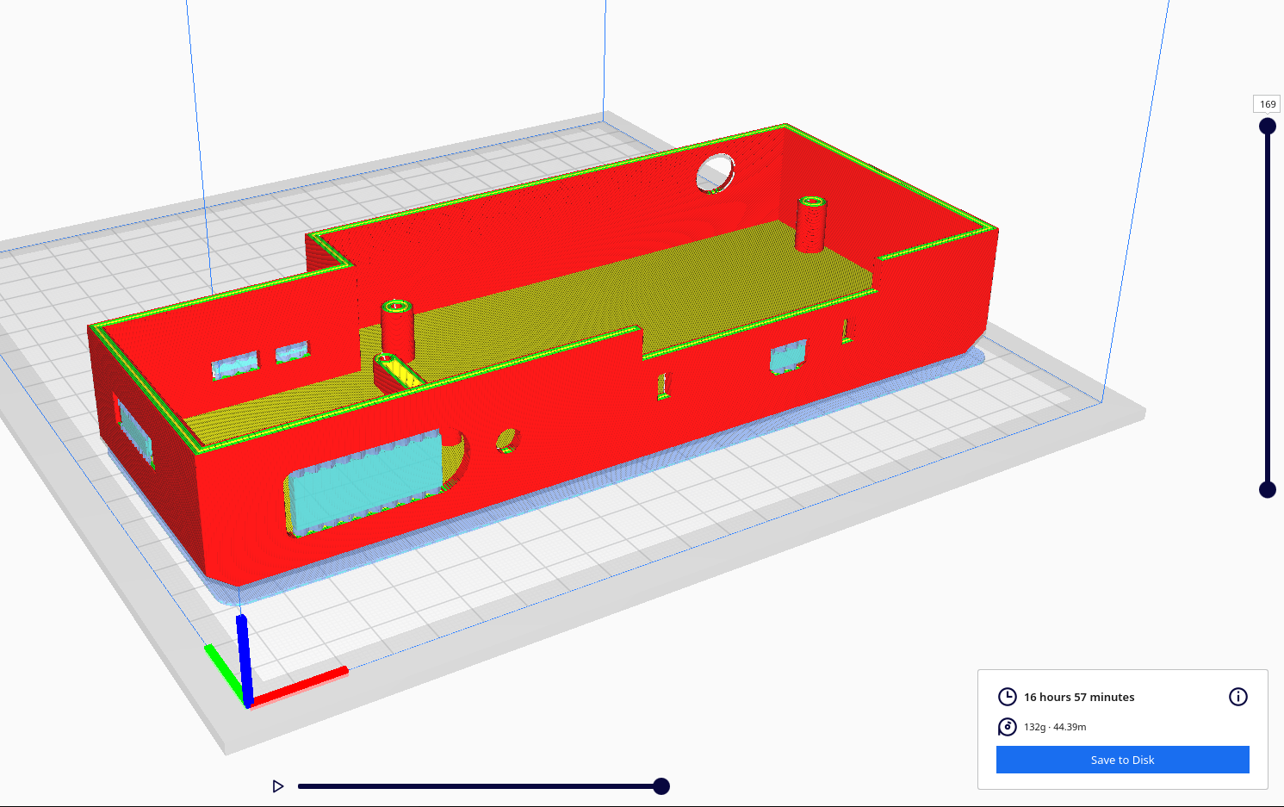
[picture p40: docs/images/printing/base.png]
Cura Sliced Base


*Picture:  Base 0.2mm Slice Shown with Raft*

The base is pretty straight forward. If you want to print without a raft more power to you, you will save time doing so. However if you're having adhesion problems or your bottom looks scuffed, a raft will solve your issues and no one cares about the bottom of your case.

You will notice with the support modifications lots of places without supports and that is intentional because it's overkill otherwise- **fun fact**, you could print this entirely without supports too- I did it sometimes during prototyping and it worked, but you might get some sagging from the SNES/SFC port sometimes. The settings I recommend are easy to remove yet provide good support to the places that need it.

## The Lid
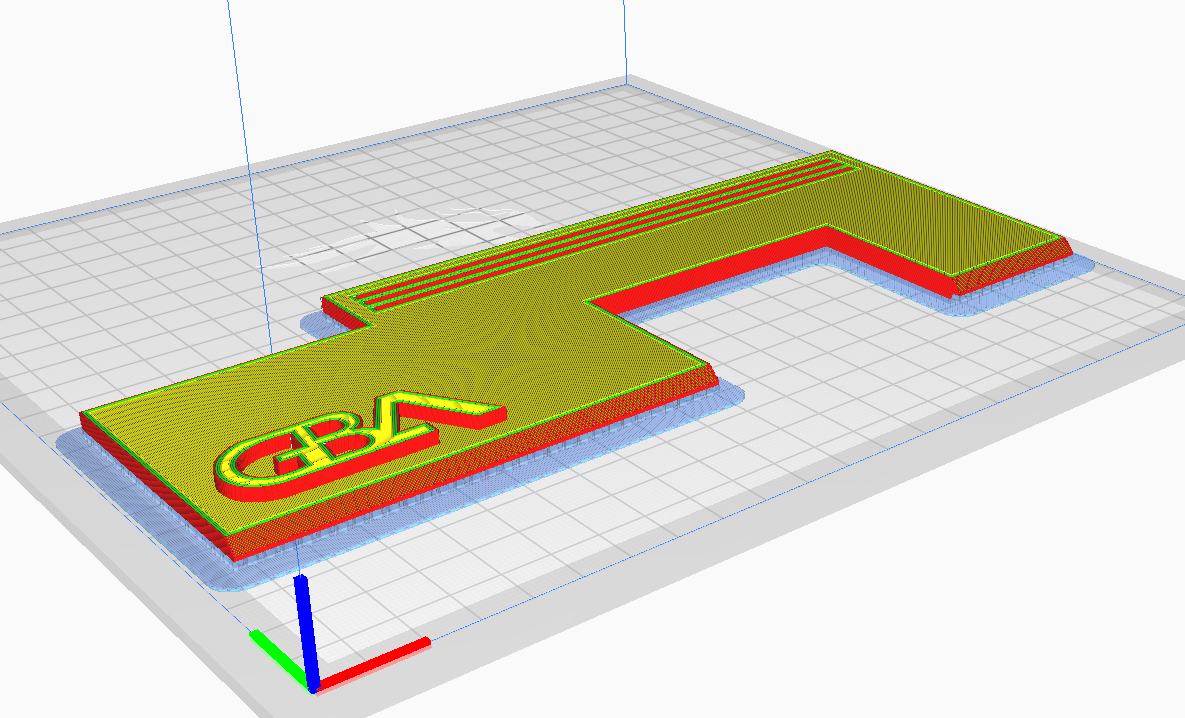
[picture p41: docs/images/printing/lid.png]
Cura Sliced Lid

*Picture: Lid 0.2mm Slice Shown with Raft*

**The lid should absolutely be built on a raft no exceptions.** Why? it makes it so easy to just rip off the supports. In one peel everything  should come off. And if you're using the no logo variation you might think you're clever to flip it around and print face down- unless you have a perfect bed, with perfect leveling, with perfect heat and adhesion you will get a scuffed face and warping. The best thing to do is raft it and call it a day.

## Some 3D Printing Tuning Resources
Despite its looks, it can be a hard print because of its size and density. However, I honestly recommend these videos and tools to help tune in your 3D printer before getting to work:

https://teachingtechyt.github.io/calibration.html

## (Extra) Good BLTouch Start Code for Ender 3
This is what I use for most of my prints, I stole it from reddit somewhere, I am owed no credit. Just place this in your printer settings in your slicer.

```
; Ender 3 Custom Start G-code
M140 S{material_bed_temperature_layer_0} ; Set Heat Bed temperature
M190 S{material_bed_temperature_layer_0} ; Wait for Heat Bed temperature
M104 S160; start warming extruder to 160
G28 ; Home all axes
G29 ; Auto bed-level (BL-Touch)
G92 E0 ; Reset Extruder
M104 S{material_print_temperature_layer_0} ; Set Extruder temperature
G1 X0.1 Y20 Z0.3 F5000.0 ; Move to start position
M109 S{material_print_temperature_layer_0} ; Wait for Extruder temperature
; G1 Z2.0 F3000 ; Move Z Axis up little to prevent scratching of Heat Bed
G1 X0.1 Y200.0 Z0.3 F1500.0 E15 ; Draw the first line
G1 X0.4 Y200.0 Z0.3 F5000.0 ; Move to side a little
G1 X0.4 Y20 Z0.3 F1500.0 E30 ; Draw the second line
G92 E0 ; Reset Extruder
G1 Z2.0 F3000 ; Move Z Axis up little to prevent scratching of Heat Bed
; End of custom start GCode
```
